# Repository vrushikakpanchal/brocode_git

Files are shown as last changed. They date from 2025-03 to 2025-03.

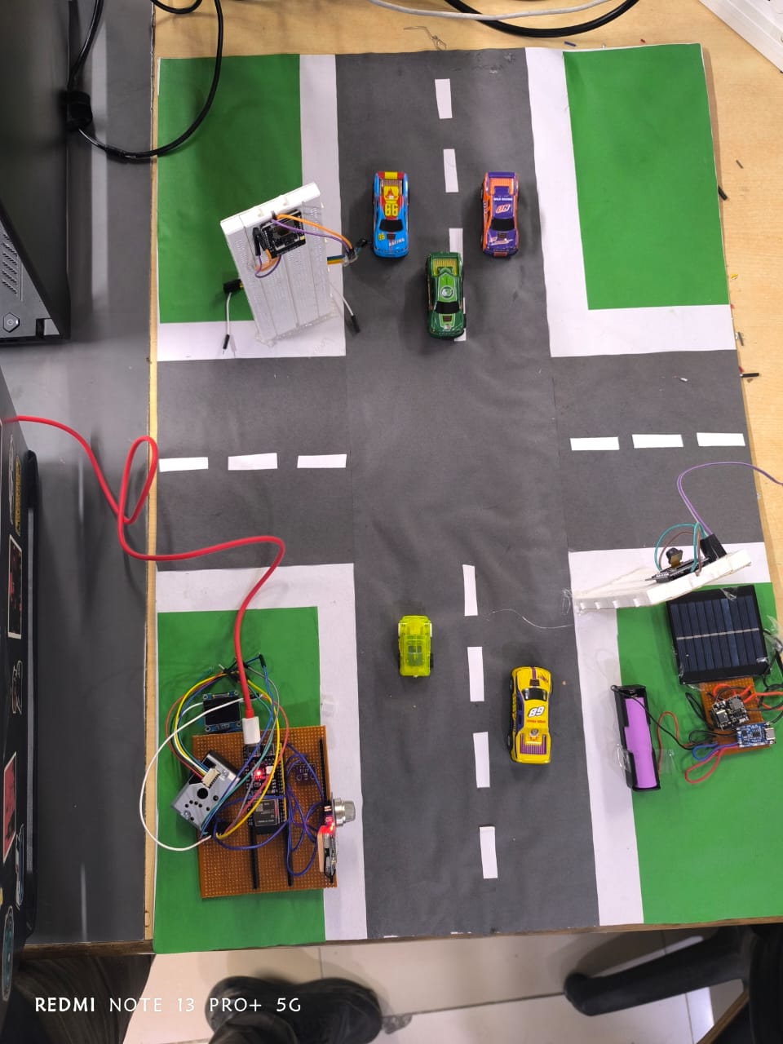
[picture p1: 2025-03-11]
03_project_images/img5.jpg

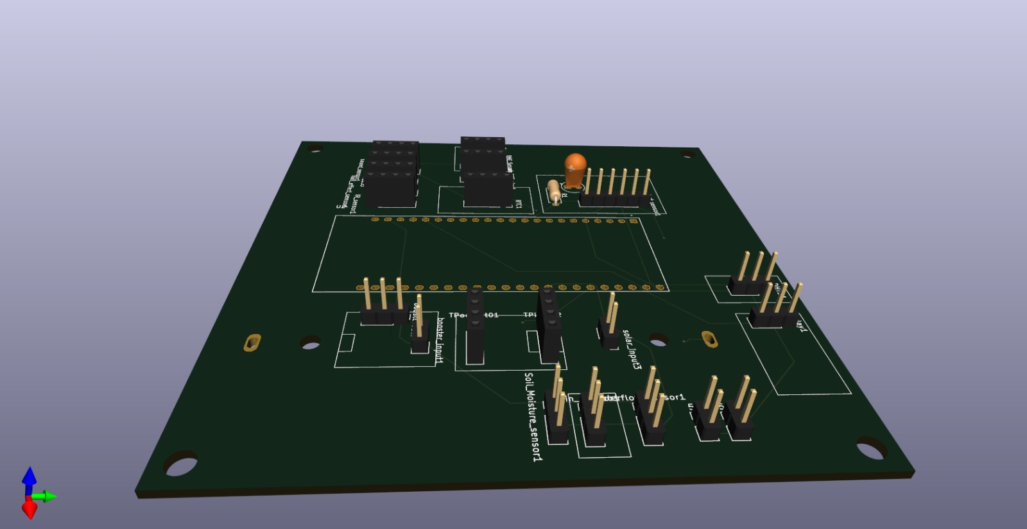
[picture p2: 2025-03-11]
03_project_images/img7.jpg

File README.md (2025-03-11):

# UnPlugged 2.0 - Smart City Sentinel

## Overview
This project was developed as part of **UnPlugged 2.0**, a 24-hour hardware hackathon organized by Shri Vile Parle Kelavani Mandal's Dwarkadas J. Sanghvi College of Engineering. Our solution focuses on **AI-driven IoT & GIS-based urban intelligence** to optimize traffic management, environmental monitoring, and public safety.

## Problem Statement
With rapid urbanization, cities face challenges in managing infrastructure, optimizing resources, and ensuring public safety. Existing systems often react too slowly, leading to inefficiencies. Our task was to **engineer an autonomous system** integrating:
- **IoT-based urban monitoring**
- **Multi-sensor data fusion**
- **Geographic Information System (GIS)**
- **AI models for traffic control, emergency response, and environmental monitoring**
- **Decentralized edge AI for real-time decision-making**

## Solution Implemented
### **1. Traffic Flow Optimization** 🚦
- **ESP32 cameras** placed across **4 lanes** to monitor vehicle density.
- AI logic to **prioritize lane clearance** based on congestion levels.

### **2. Environmental Monitoring** 🌍
- Hardware setup includes sensors for **AQI, dust, and temperature levels**.
- Data is **transmitted in real-time** to a **cloud-based dashboard**.

### **3. User Dashboard & Access** 🖥️
- **Two types of logins:**
  - **Admin (Traffic Police):** Controls signal timings.
  - **User:** Accesses live traffic updates and environmental data.
- **Web-based dashboard** for real-time monitoring.

## Tech Stack & Components
- **Hardware:** ESP32-CAM, air quality sensors, temperature sensors, solar-powered PCB
- **Software:** KiCad (PCB design), Python, Flask, React.js
- **Cloud & AI:** Firebase, Edge AI for anomaly detection

## Team Members 👥
- Vrushika Panchal [Diploma - AI/ML]
- Harsh Pandey [B.Tech - EXTC]
- Soham Nagvekar [B.Tech - EXTC]
- Prasad Rane [B.Tech - EXTC]
- Atharva Wadekar [B.Tech - EXTC]
- Advait Shinde [Diploma - AI/ML]

## Repository Structure
```
📂 brocode_git
 ┣ 📂 01_Kicad_PCB        # KiCad PCB designs
 ┣ 📂 02_GERBER           # ESP32 & IoT sensor integration
 ┣ 📂 03_project_images           # React.js frontend for monitoring
 ┣ 📂 04_frontend_website               # Traffic analysis & anomaly detection
 ┣ 📜 README.md               # Project documentation
```

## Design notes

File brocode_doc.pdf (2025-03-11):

## UNPLUGGED 2.0 – 24 - Hour Hardware Hackathon

## Round 2

## Team Name: Brocode

## Team Members:

## Harsh Pandey [ B.tech - EXTC ]

## Soham Nagvekar [ B.tech – EXTC ]

## Prasad Rane [ B.tech – EXTC ]

## Atharva Wadekar [ B.tech – EXTC ]

## Advait Shinde [ Diploma – AI ML ]

## Vrushika Panchal [ Diploma – AI ML ]

## Table of Content

Overview

Design and Electrical Rule Checks

Pin mapping and component placement

No. of components used

Overall Layout

Documentation

Final PCB

Total

OVERVIEW

PROBLEM STATEMENT

With rapid urbanization, real-time environmental monitoring has become essential for sustainable city planning. The Smart City Sentinel project addresses this need by developing a modular PCB that integrates sensors, power management, and communication protocols. This enables seamless data collection and transmission, ensuring efficient environmental surveillance in urban areas.

INTRODUCTION

The Smart City Sentinel project focuses on designing a modular PCB using KiCad to facilitate real-time environmental monitoring. The PCB incorporates sensor interfacing, power management, and efficient data transmission within a scalable and optimized architecture. Adhering to competition constraints, the design features a two-layer PCB, standardized components, and optimized connectivity, ensuring seamless functionality and future scalability.

ABSTRACT

The Smart City Sentinel is an advanced modular PCB designed for intelligent eenvironmental surveillance. It integrates multiple sensors, a robust power management system with solar panel support, and structured communication protocols to enable real-time data collection and transmission. The design prioritizes modularity, allowing for future enhancements with minimal modifications, while strictly adhering to power and connectivity constraints. Additionally, a precision-engineered 3D CAD model ensures a seamless structural fit with a predefined solar panel, enhancing its practical usability and real-world implementation.

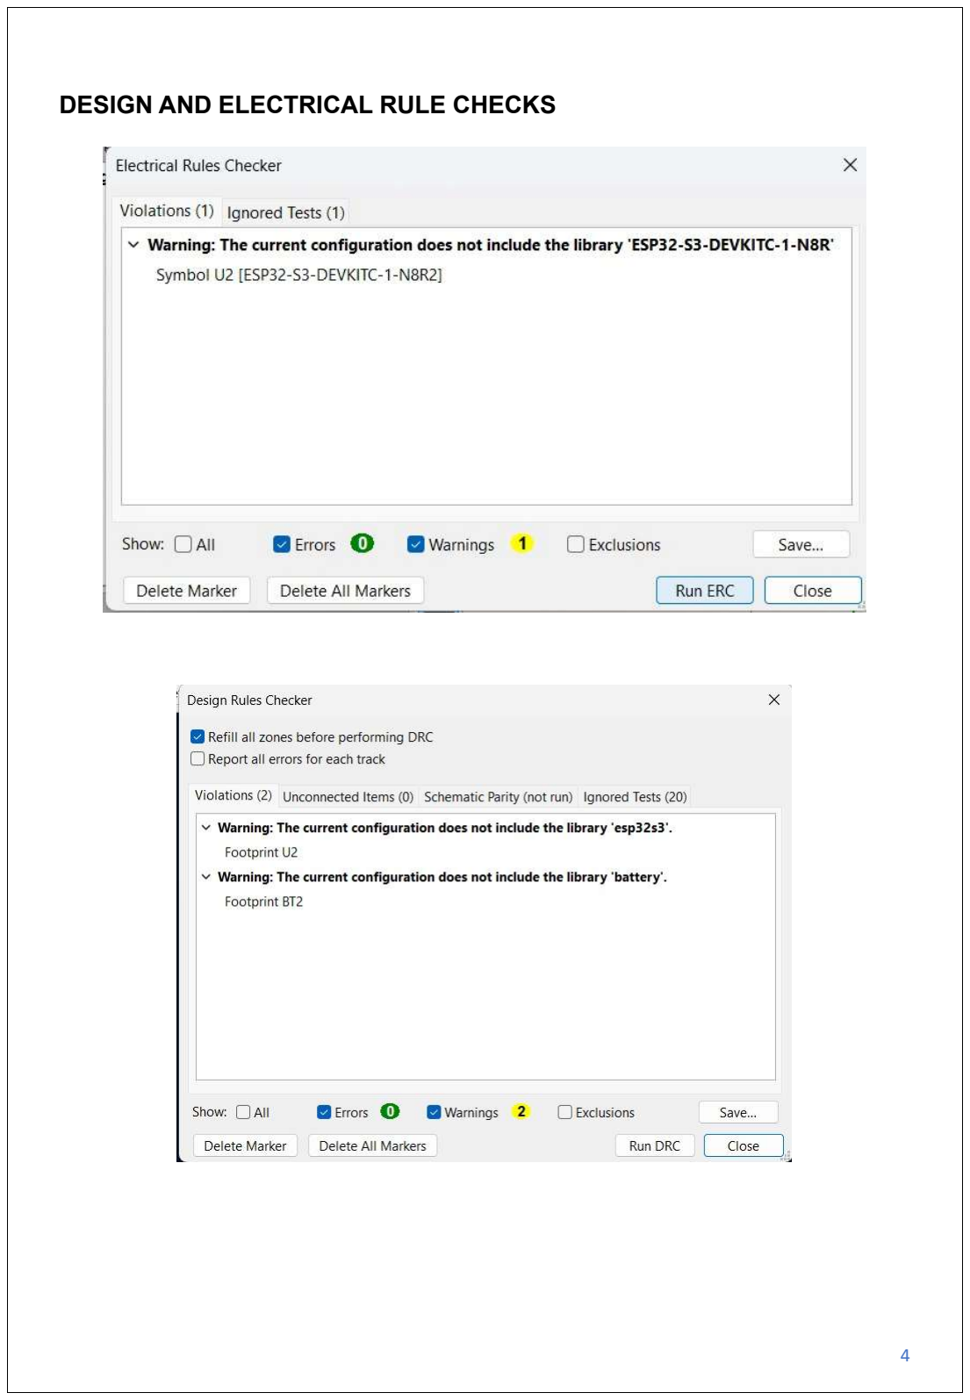
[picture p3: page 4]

DESIGN AND ELECTRICAL RULE CHECKS

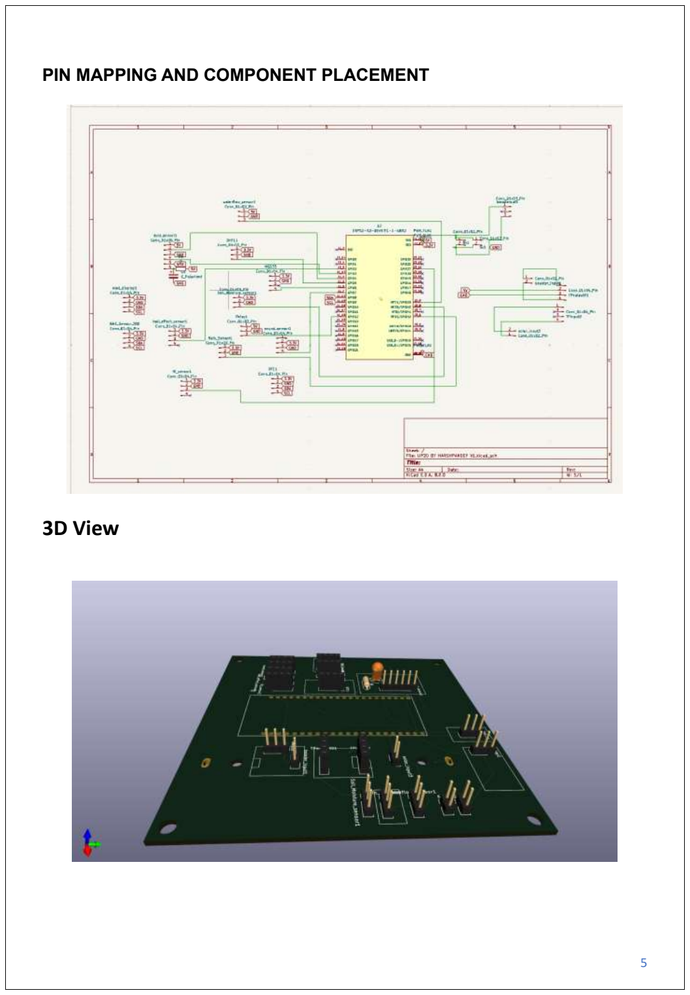
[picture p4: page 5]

PIN MAPPING AND COMPONENT PLACEMENT

## 3D View

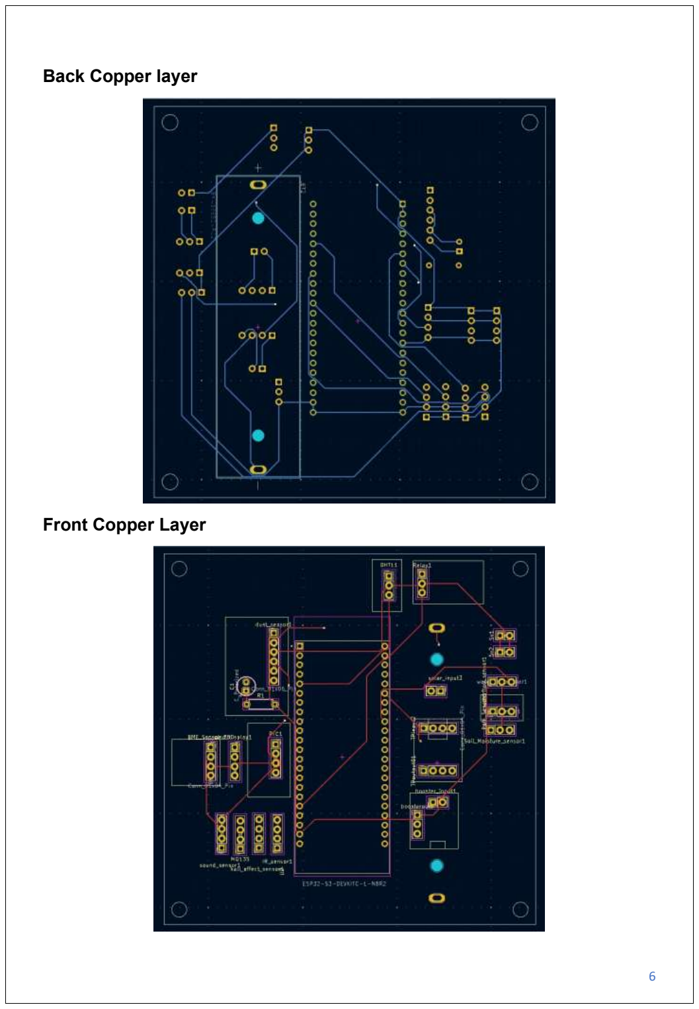
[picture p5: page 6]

Back Copper layer

Front Copper Layer

NO. OF COMPONENTS USED

Bill of Material

Components | Quantity | Price
ESP32-53 Dev module | 1 | ₹ 1,458.00
MQ-135 Gas Sensor | 1 | ₹ 139.00
Sound Sensor Module | 1 | ₹ 37.00
OLED Display | 1 | ₹ 289.00
BME280 Environmental Sensor | 1 | ₹ 44.00
Solar Panel | 1 | ₹ 189.00
Rechargeable Module (TP4056) | 1 | ₹ 24.00
IR Flame Sensor | 1 | ₹ 69.00
Battery 3.7v 2500mAh 18560 | 1 | ₹ 800.00
Voltage Booster | 1 | ₹ 49.00
Dust Sensor | 1 | ₹ 599.00
Hall Effect Sensor | 1 | ₹ 34.00
MAX471 Current and Voltage Sensor | 1 | ₹ 399.00
Water Flow Sensor | 1 | ₹ 236.00
DHT11 Temperature and Humidity Sensor | 1 | ₹ 90.00
Soil Moisture Sensor | 1 | ₹ 189.00
Relay Module | 1 | ₹ 199.00
Rain Sensor | 1 | ₹ 156.00
RTC DS3231 module | 1 | ₹ 122.00
TOTAL | ₹ 5,122.00

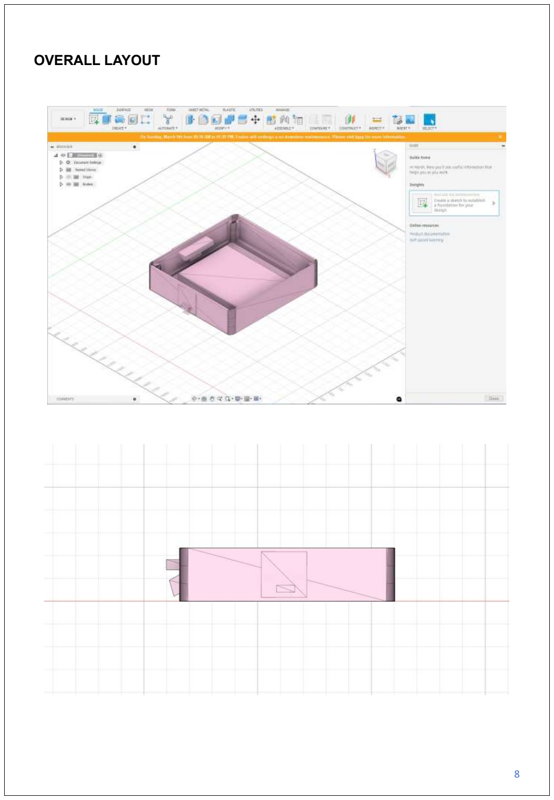
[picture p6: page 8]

OVERALL LAYOUT

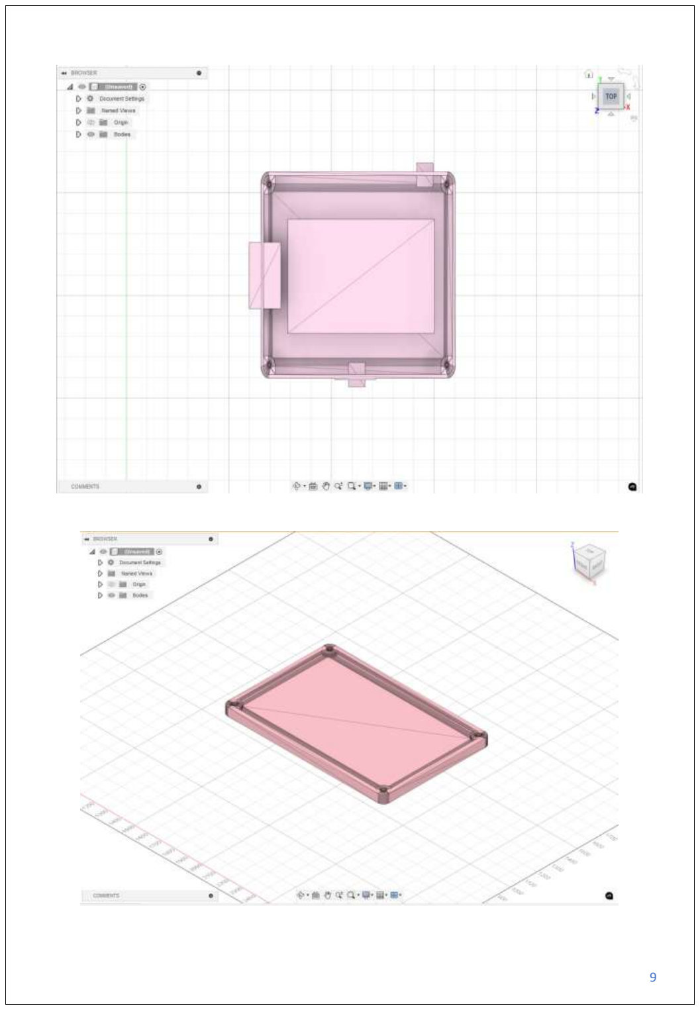
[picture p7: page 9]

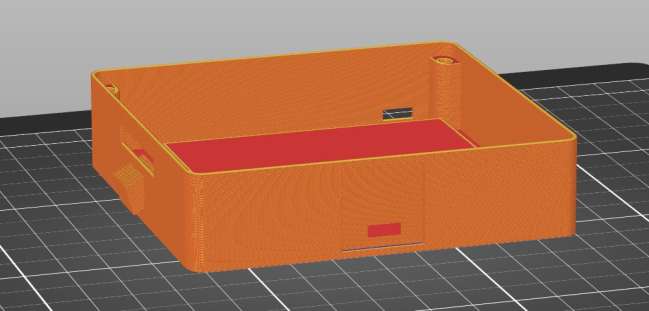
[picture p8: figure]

The 3D-printed enclosure protects the ESP32-S3 and camera module for traffic rule monitoring. It features cutouts for wiring, ventilation, and the camera lens, with a secure screw-on bottom cover. Designed for durability and outdoor use, it ensures stable image capture and processing for traffic analysis.

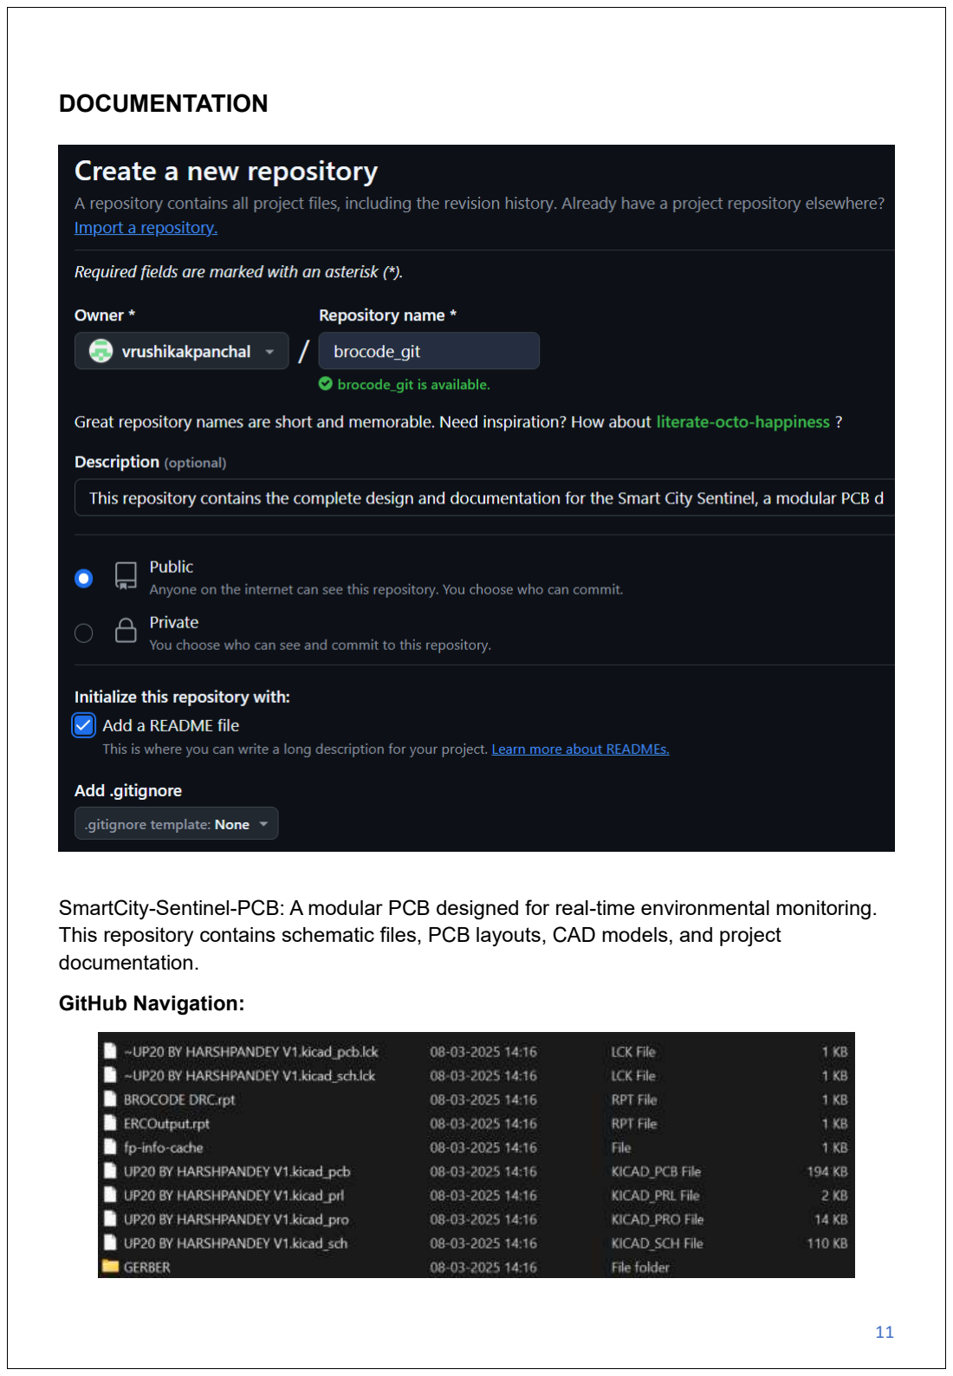
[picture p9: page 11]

DOCUMENTATION

SmartCity-Sentinel-PCB: A modular PCB designed for real-time environmental monitoring. This repository contains schematic files, PCB layouts, CAD models, and project documentation.

GitHub Navigation:

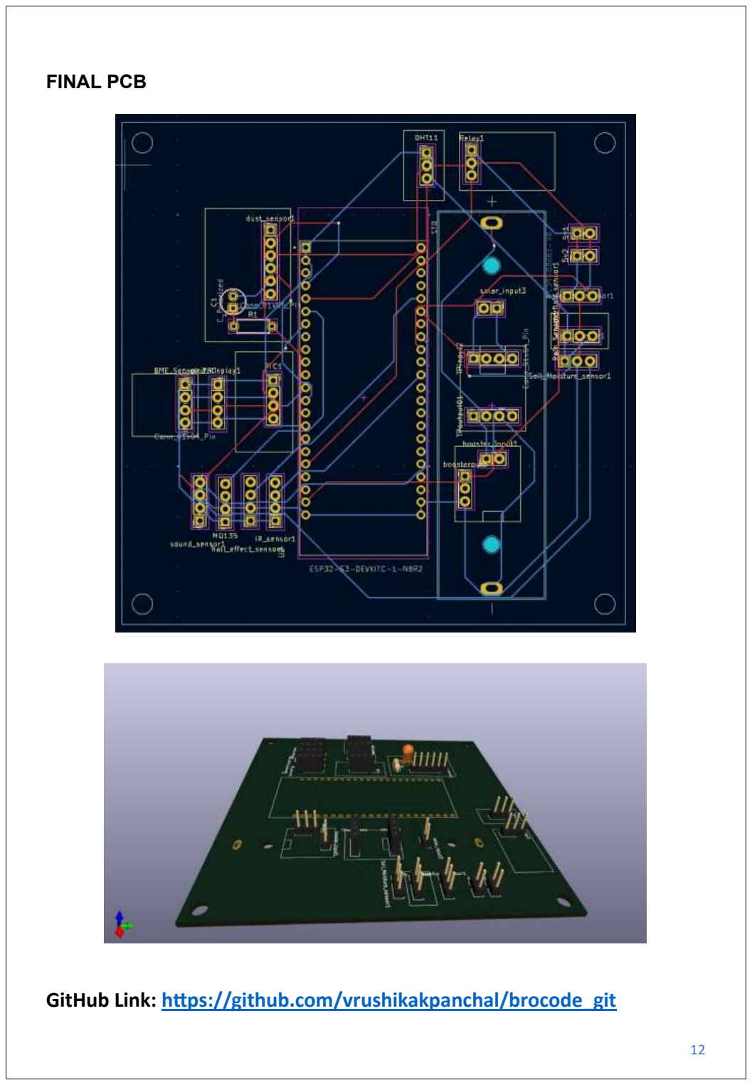
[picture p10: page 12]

FINAL PCB

### GitHub Link: https://github.com/vrushikakpanchal/brocode_git

Mentor's Suggestions for Improvement

System Overview

- Label components clearly (ESP32-S3, Camera, Server, etc.).
- Use arrows to show data flow direction.
- Apply a color scheme (blue for sensors, green for processing, red for power).

Data Flow & Processing

- Label all connections (WiFi, RFID signals, data transfer).
- Use different line styles (dashed for wireless, solid for wired).
- Add a legend to explain symbols and abbreviations.

Traffic Control & Detection

- Clearly explain the detection process step by step.
- Label emergency vehicle detection.
- Improve spacing for better readability.

Server & Database Handling

- Clarify whether data is stored locally or in the cloud.
- Show feedback loops (e.g., alerts to traffic lights).
- Use database symbols to indicate storage points.

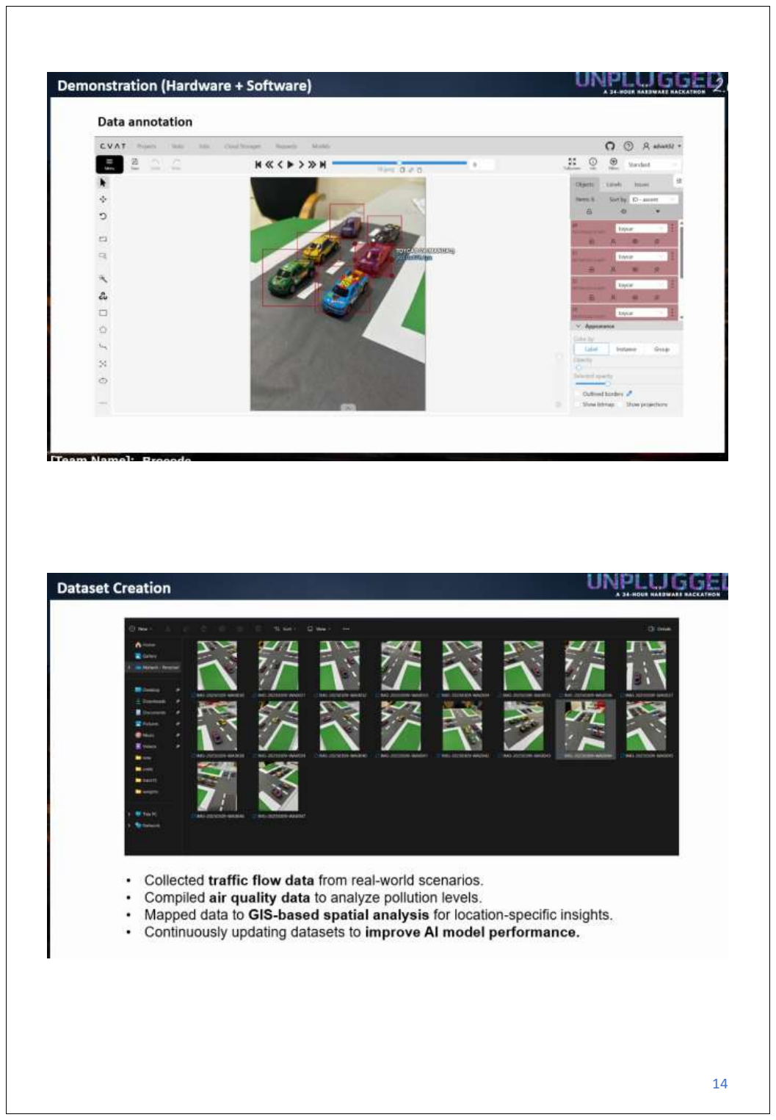
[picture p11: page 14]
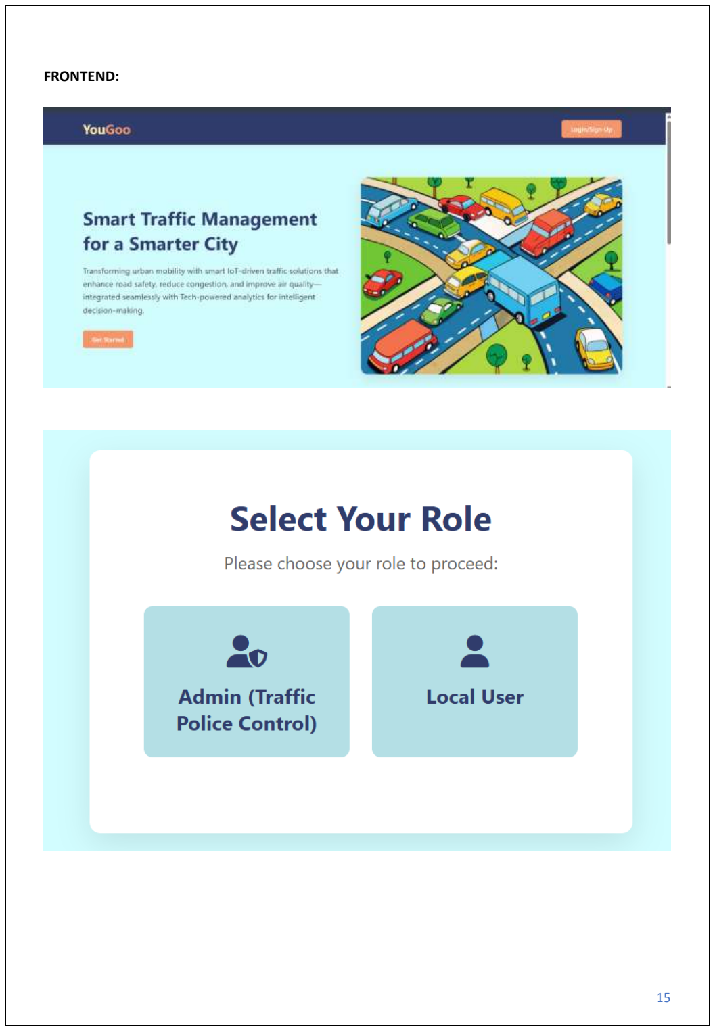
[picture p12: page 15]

FRONTEND:

FLOW:

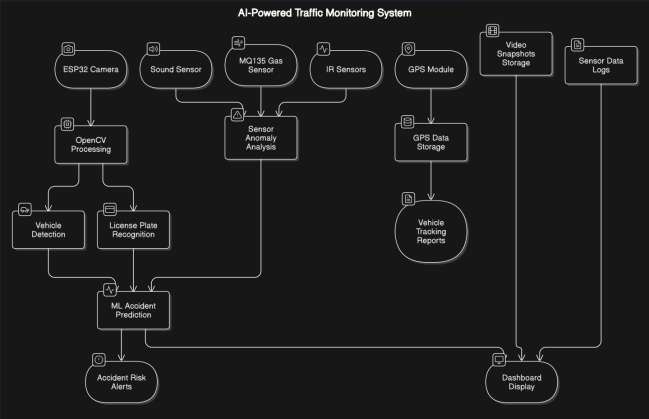
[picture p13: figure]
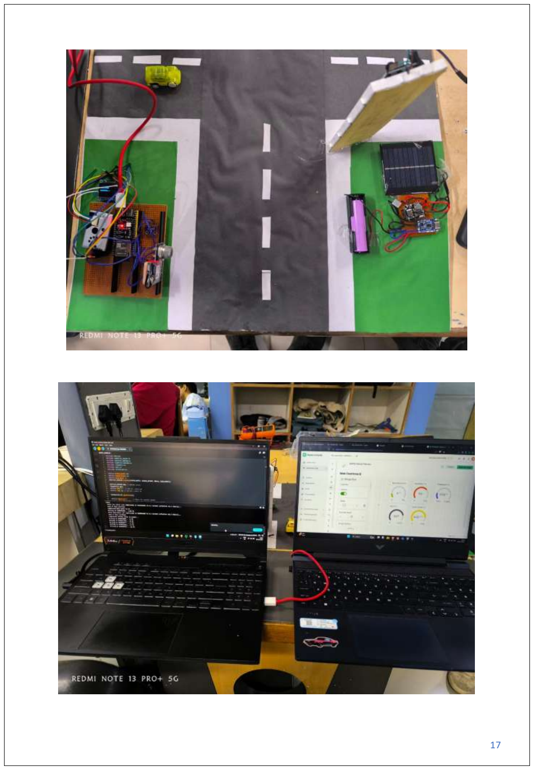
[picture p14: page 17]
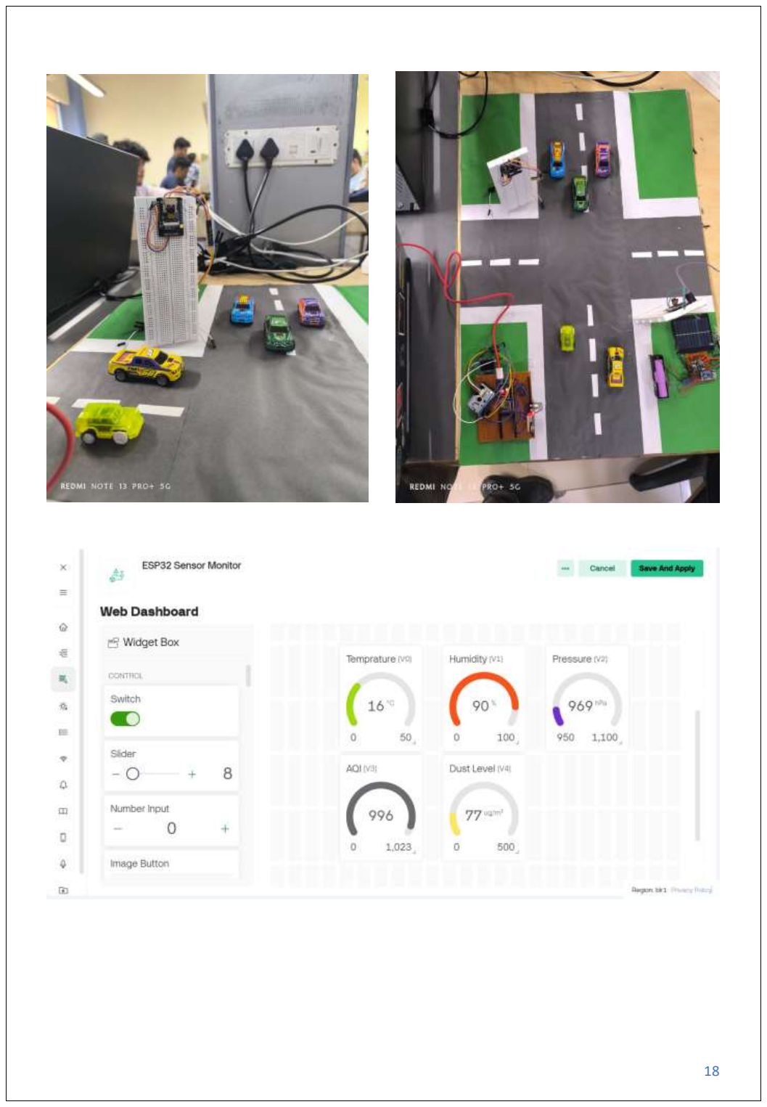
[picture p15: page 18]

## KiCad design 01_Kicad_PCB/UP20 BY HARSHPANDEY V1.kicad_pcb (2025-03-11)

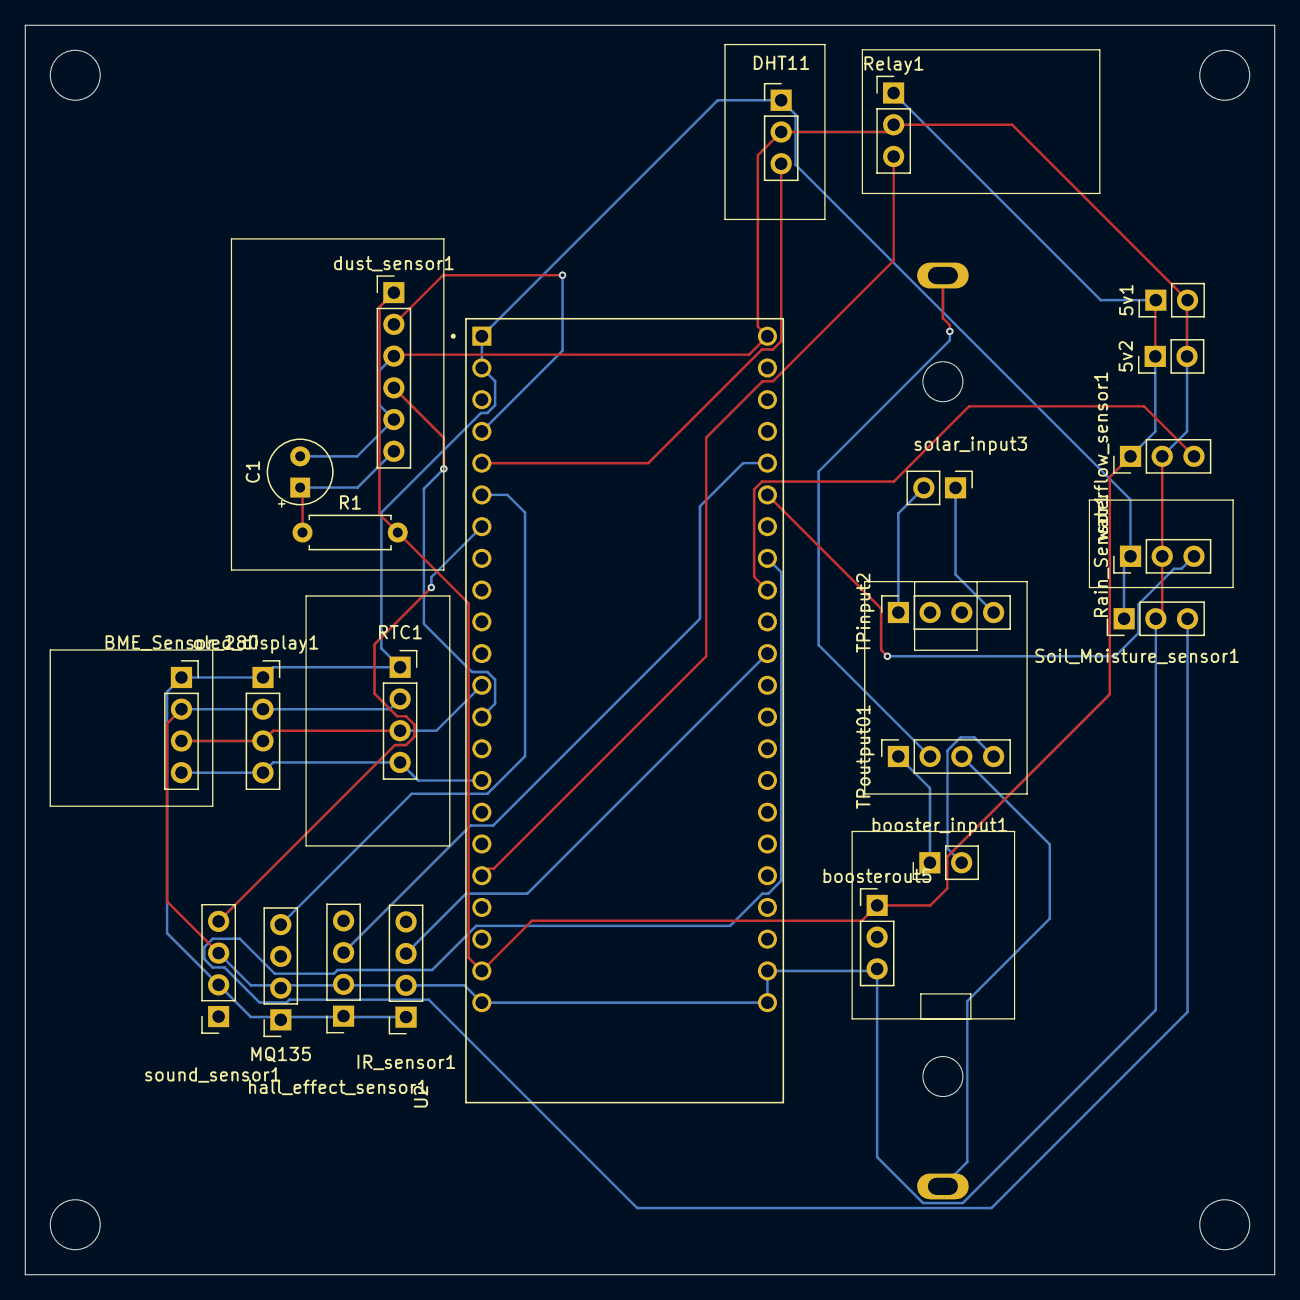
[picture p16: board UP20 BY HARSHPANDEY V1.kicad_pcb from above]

Board: 2 copper layers, 100.0 x 100.0 mm, 24 parts (1 on the bottom side), 23 nets.

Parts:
5v1, 5v2: Conn_01x02_Pin; PinHeader_1x02_P2.54mm_Vertical
BME_Sensor_280: Conn_01x04_Pin; PinSocket_1x04_P2.54mm_Vertical
BT2: BK-18650-PC2; BAT_BK-18650-PC2
C1: C_Polarized; CP_Radial_Tantal_D5.0mm_P2.50mm
DHT11: Conn_01x03_Pin; PinHeader_1x03_P2.54mm_Vertical
IR_sensor1: Conn_01x04_Pin; PinSocket_1x04_P2.54mm_Vertical
MQ135: Conn_01x04_Pin; PinSocket_1x04_P2.54mm_Vertical
R1: R; R_Axial_DIN0207_L6.3mm_D2.5mm_P7.62mm_Horizontal
RTC1: Conn_01x04_Pin; PinSocket_1x04_P2.54mm_Vertical
Rain_Sensor1: Conn_01x03_Pin; PinHeader_1x03_P2.54mm_Vertical
Relay1: Conn_01x03_Pin; PinHeader_1x03_P2.54mm_Vertical
Soil_Moisture_sensor1: Conn_01x03_Pin; PinHeader_1x03_P2.54mm_Vertical
TPinput2: Conn_01x04_Pin; PinSocket_1x04_P2.54mm_Vertical
TPoutput01: Conn_01x04_Pin; PinSocket_1x04_P2.54mm_Vertical
U2: ESP32-S3-DEVKITC-1-N8R2; XCVR_ESP32-S3-DEVKITC-1-N8R2
booster_input1: Conn_01x02_Pin; PinHeader_1x02_P2.54mm_Vertical
boosterout5: Conn_01x03_Pin; PinHeader_1x03_P2.54mm_Vertical
dust_sensor1: Conn_01x06_Pin; PinHeader_1x06_P2.54mm_Vertical
hall_effect_sensor1: Conn_01x04_Pin; PinSocket_1x04_P2.54mm_Vertical
oled_display1: Conn_01x04_Pin; PinSocket_1x04_P2.54mm_Vertical
solar_input3: Conn_01x02_Pin; PinHeader_1x02_P2.54mm_Vertical
sound_sensor1: Conn_01x04_Pin; PinSocket_1x04_P2.54mm_Vertical
waterflow_sensor1: Conn_01x03_Pin; PinHeader_1x03_P2.54mm_Vertical

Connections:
3.3V: BME_Sensor_280.1, DHT11.1, IR_sensor1.1, MQ135.1, RTC1.1, Rain_Sensor1.1, Soil_Moisture_sensor1.1, U2.J1_1 (3V3), U2.J1_2 (3V3), hall_effect_sensor1.1, oled_display1.1, sound_sensor1.2
5V: 5v1.1, 5v2.1, R1.2, Relay1.1, U2.J1_21 (5V0), boosterout5.1, dust_sensor1.1, waterflow_sensor1.1
GND: 5v1.2, 5v2.2, BME_Sensor_280.2, C1.2, DHT11.2, IR_sensor1.2, MQ135.2, RTC1.2, Rain_Sensor1.2, Relay1.2, Soil_Moisture_sensor1.2, U2.J1_22 (GND), U2.J3_1 (GND), U2.J3_21 (GND), U2.J3_22 (GND), boosterout5.3, dust_sensor1.3, dust_sensor1.5, hall_effect_sensor1.2, oled_display1.2, sound_sensor1.3, waterflow_sensor1.2
unnamed: DHT11.3, U2.J1_5 (GPIO5)
unnamed: IR_sensor1.3, U2.J3_11 (GPIO37)
unnamed: MQ135.4, U2.J1_6 (GPIO6)
unnamed: Rain_Sensor1.3, U2.J3_6 (MTMS/GPIO42)
unnamed: Relay1.3, U2.J1_18 (GPIO12)
unnamed: Soil_Moisture_sensor1.3, U2.J3_8 (MTDO/GPIO40)
unnamed: TPinput2.1, solar_input3.2
unnamed: TPinput2.4, solar_input3.1
unnamed: TPoutput01.1, booster_input1.1
unnamed: BT2.+, TPoutput01.2
unnamed: BT2.-, TPoutput01.3
unnamed: TPoutput01.4, booster_input1.2
unnamed: U2.J3_5 (GPIO2), hall_effect_sensor1.3
unnamed: U2.J1_13 (GPIO3), dust_sensor1.4
unnamed: U2.J1_4 (GPIO4), dust_sensor1.2
unnamed: U2.J1_7 (GPIO7), sound_sensor1.4
unnamed: U2.J3_9 (MTCK/GPIO39), waterflow_sensor1.3
unnamed: C1.1, R1.1, dust_sensor1.6
SCL: BME_Sensor_280.4, RTC1.4, U2.J1_15 (GPIO9), oled_display1.4
SDA: BME_Sensor_280.3, RTC1.3, U2.J1_12 (GPIO8), oled_display1.3

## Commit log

2025-03-11 Removed all existing files
    [UP20 BY HARSHPANDEY V1.kicad_pcb, UP20 BY HARSHPANDEY V1.kicad_sch, bob.xlsx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]
2025-03-11 Ignore large video files
    [UP20 BY HARSHPANDEY V1-NPTH.drl, UP20 BY HARSHPANDEY V1-PTH.drl]
2025-03-11 Added 01_Kicad_PCB
    [UP20 BY HARSHPANDEY V1.kicad_pcb, UP20 BY HARSHPANDEY V1.kicad_sch]
